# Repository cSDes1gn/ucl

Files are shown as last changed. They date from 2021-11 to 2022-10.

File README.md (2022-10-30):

# Automated Under Cabinet Lighting


Modified: 2022-10

Under cabinet lighting (ucl) control system.

## License
This project is licensed under the terms of the [MIT License](LICENSE)

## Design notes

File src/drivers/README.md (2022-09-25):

# Hardware Peripheral Drivers

Modified: 2022-09

These modules are hardware abstraction layer endpoints for hardware transactions between processors or other hardware peripherals. Hardware drivers should be lightweight and follow the Hardware Proxy design pattern.

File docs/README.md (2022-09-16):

# Documentation

## Installations
```bash
brew tap osx-cross/avr
brew install avr-gcc avrdude
```

## Compile and Flash
Using `CMake` toolchain:
```bash
mkdir build
cd build
cmake ..
make -j
make flash
```

Using `avrdude` and `avr-gcc` utilities
```bash
# compile
avr-gcc main.c usart.c -DF_CPU=16000000 -mmcu=atmega2560 -Wall -Werror -Wextra -Os
# translate to hex
avr-objcopy -j .text -j .data -O ihex a.out my.hex
# flash
avrdude -patmega2560 -cwiring -P/dev/ttyACM0 -b115200 -D -Uflash:w:my.hex:i
```

## Important Links
1. https://www.nongnu.org/avrdude/user-manual/avrdude_toc.html#SEC_Contents
2. https://ww1.microchip.com/downloads/en/devicedoc/atmel-2549-8-bit-avr-microcontroller-atmega640-1280-1281-2560-2561_datasheet.pdf

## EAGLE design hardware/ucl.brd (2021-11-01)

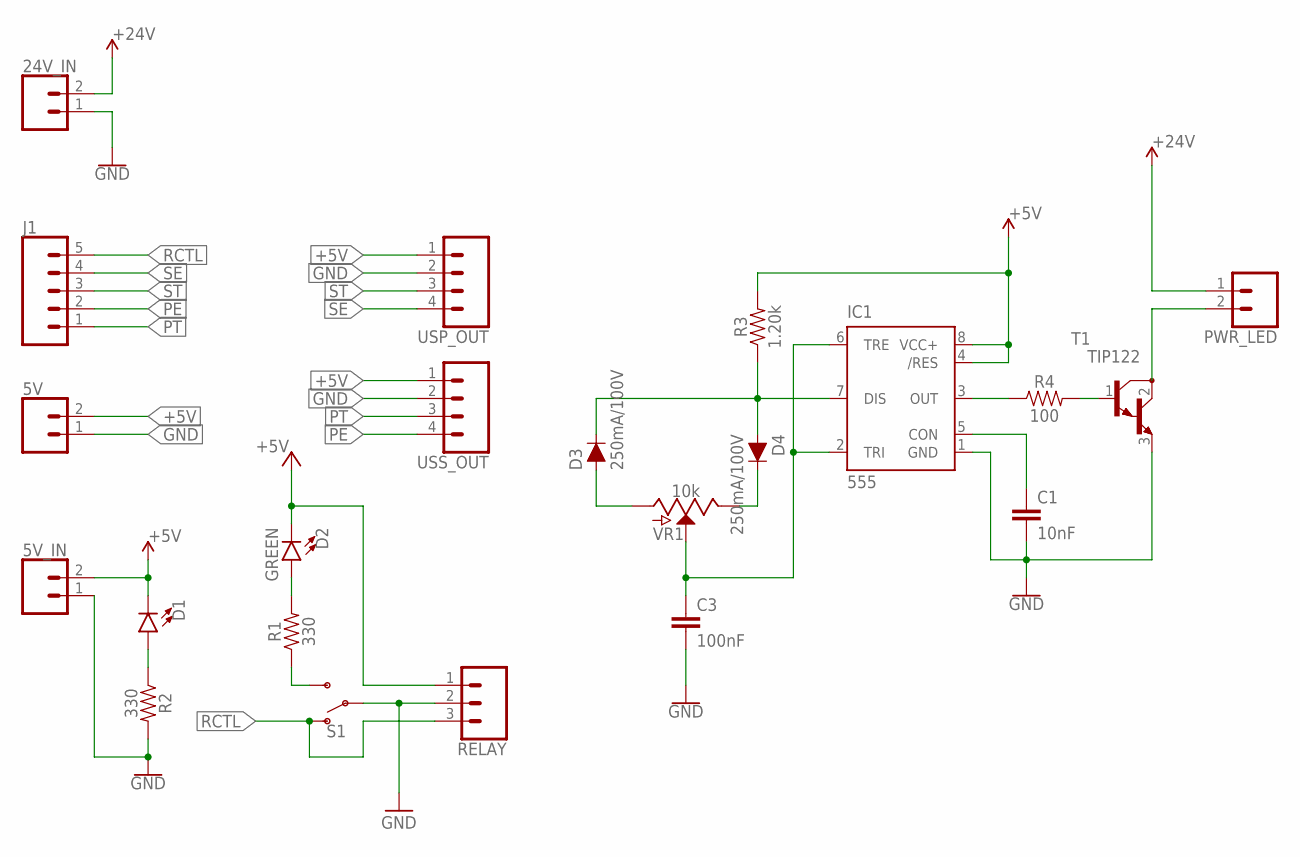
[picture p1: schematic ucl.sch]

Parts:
5V: CONN_02POLAR; MOLEX-1X2
5V_IN, 24V_IN: CONN_02POLAR_LOCK; MOLEX-1X2_LOCK
C1: 10nF; 0402-TIGHT
C3: 100nF; 0402-TIGHT
D1: LED1206; LED-1206
D2: GREEN; LED-1206
D3, D4: 250mA/100V; SOD-323
IC1: 555; SO08
J1: CONN_05; 1X05
PWR_LED: CONN_02POLAR_LOCK; MOLEX-1X2_LOCK
R1, R2: 330; 0603
R3: 1.20k; 0603
R4: 100; 0603
RELAY: CONN_03POLAR_LOCK; MOLEX-1X3_LOCK
S1: SWITCH-SPDT-PTH-11.6X4.0MM-KIT; SWITCH_SPDT_PTH_11.6X4.0MM_KIT
T1: TIP122; TO220
USP_OUT: CONN_04POLAR_LOCK; MOLEX-1X4_LOCK
USS_OUT: CONN_04POLAR_LOCK; MOLEX-1X4_LOCK
VR1: 10k; POT-PTH-ALPS

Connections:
+5V: 5V.2, 5V_IN.2, D1.C, D2.C, IC1.4 (/RES), IC1.8 (VCC+), R3.2, RELAY.1, USP_OUT.1, USS_OUT.1
+24V: 24V_IN.2, PWR_LED.1
GND: 5V.1, 5V_IN.1, 24V_IN.1, C1.2, C3.2, IC1.1 (GND), R2.2, RELAY.2, S1.2, T1.3 (E), USP_OUT.2, USS_OUT.2
unnamed: R1.1, S1.3 (S)
unnamed: D2.A, R1.2
unnamed: D1.A, R2.1
unnamed: D3.C, D4.A, IC1.7 (DIS), R3.1
unnamed: D3.A, VR1.P$3 (A)
unnamed: D4.C, VR1.P$1 (E)
unnamed: C3.1, IC1.2 (TRI), IC1.6 (TRE), VR1.P$2 (S)
unnamed: IC1.3 (OUT), R4.1
unnamed: R4.2, T1.1 (B)
unnamed: C1.1, IC1.5 (CON)
unnamed: PWR_LED.2, T1.2 (C)
PE: J1.2, USS_OUT.4
PT: J1.1, USS_OUT.3
RCTL: J1.5, RELAY.3, S1.1 (O)
SE: J1.4, USP_OUT.4
ST: J1.3, USP_OUT.3

Board: 2 copper layers, 22 parts (0 on the bottom side), 19 nets, no tracks yet.

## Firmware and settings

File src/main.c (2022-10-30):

#include <avr/cpufunc.h>
#include <avr/interrupt.h>
#include <avr/io.h>

#include "encoder.h"
#include "logger.h"
#include "tests.h"
#include "usart.h"

void spinlock(void) {
  while (1) {
    _NOP();
  }
}

int main(void) {
  logger_set_level(LOG_TRACE);
  usart_init();
  encoder_init();
  sei();
  // test_run("EEPROM", test_eeprom);
  // test_run("PWM", test_pwm);
  for (;;) {
    info("Encoder Event: %u", encoder_next_event());
  }
  info("Task complete, entering spinlock.");
  spinlock();
  return 0;
}

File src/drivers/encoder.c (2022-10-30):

#include "encoder.h"

#include <avr/interrupt.h>
#include <avr/io.h>

#include "cbuf.h"
#include "logger.h"

/**
 * @brief All Rotary encoder signals will be handled by PCINT2
 *  SW -> PK3 (PCINT19)
 *  DT -> PK4 (PCINT20)
 *  CLK -> PK5 (PCINT21)
 */

/**
 * @brief Implement table encoding method.　Below are the table state encodings:
 *
 * INVALID = 0
 * CW = 1
 * CCW = 2
 *
 * [PCLK PDT CLK DT | STATE | CODE ]
 *  0 0 0 0 | PASSIVE | 0
 *  0 0 0 1 | CCW     | 2
 *  0 0 1 0 | CW      | 1
 *  0 0 1 1 | INVALID | 0
 *  0 1 0 0 | CW      | 1
 *  0 1 0 1 | PASSIVE | 0
 *  0 1 1 0 | INVALID | 0
 *  0 1 1 1 | CCW     | 2
 *  1 0 0 0 | CCW     | 2
 *  1 0 0 1 | INVALID | 0
 *  1 0 1 0 | PASSIVE | 0
 *  1 0 1 1 | CW      | 1
 *  1 1 0 0 | INVALID | 0
 *  1 1 0 1 | CW      | 1
 *  1 1 1 0 | CCW     | 2
 *  1 1 1 1 | PASSIVE | 0
 */

static volatile uint8_t pre_state = 0;
static volatile enum encoder_event events[ENCODER_EVENT_BUF_LEN];
static cbuf_t cbuffer;

static enum encoder_event encoder_map[] = {
    ENCODER_NULL, ENCODER_CCW,  ENCODER_CW,   ENCODER_NULL,
    ENCODER_CW,   ENCODER_NULL, ENCODER_NULL, ENCODER_CCW,
    ENCODER_CCW,  ENCODER_NULL, ENCODER_NULL, ENCODER_CW,
    ENCODER_NULL, ENCODER_CW,   ENCODER_CCW,  ENCODER_NULL};

/**
 * @brief
 *
 */
ISR(PCINT2_vect) {
  cli();
  if (!(PINK & (1 << PK3))) {
    trace("PUSH");
    cbuf_put(&cbuffer, ENCODER_SW);
  }
  uint8_t re_state = PINK & ((1 << PK4) | (1 << PK5));
  // translate for concat
  re_state >>= 4;
  uint8_t idx = ((pre_state << 2) | re_state) & 0x0f;
  enum encoder_event state = encoder_map[idx];
  switch (state) {
    case ENCODER_CW:
      trace("CW");
      cbuf_put(&cbuffer, ENCODER_CW);
      break;
    case ENCODER_CCW:
      trace("CCW");
      cbuf_put(&cbuffer, ENCODER_CCW);
      break;
    case ENCODER_NULL:
      break;
    default:
      break;
  }
  // save previous state
  pre_state = re_state;
  sei();
}

void encoder_init(void) {
  // set rotary encoder inputs
  DDRK &= ~((1 << PK5) | (1 << PK4) | (1 << PK3));
  // enable pullups
  PORTK |= (1 << PK5) | (1 << PK4) | (1 << PK3);
  // setup interrupt mask for PCINT2 vector
  PCMSK2 |= (1 << PCINT21) | (1 << PCINT20) | (1 << PCINT19);
  // wake scan on PCINT23:16
  PCICR |= (1 << PCIE2);
  // setup event circular buffer
  cbuffer = cbuf_init((uint8_t *)events, ENCODER_EVENT_BUF_LEN);
  trace("encoder driver init success.");
}

void encoder_clear_events(void) {
  cli();
  cbuf_reset(&cbuffer);
  sei();
  trace("reset encoder event queue");
}

enum encoder_event encoder_next_event(void) {
  enum encoder_event event;
  cli();
  if (cbuf_get(&cbuffer, (uint8_t *)&event) == CBUF_EMPTY) {
    event = ENCODER_NULL;
  }
  sei();
  return event;
}

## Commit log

2021-11-01 adding eagle hardware project files
    [ucl.brd, ucl.sch]
2021-11-01 add arduino src code
2022-09-06 sample usart program
2022-09-07 basic cmake toolchain for fuse setting and compilation
2022-09-07 fix fuse target
2022-09-09 write basic eeprom driver
2022-09-09 hack prints
2022-09-10 deprecate arduino api work
2022-09-10 add usart printlf
2022-09-13 add configuration include for general microchip config
    [configuration.h]
2022-09-13 implement 8 bit phase correct PWM stimulus on PL3
    [main.c, pwm.c, pwm.h]
2022-09-15 add pwm sweep test
2022-09-15 fix pwm wake
2022-09-15 pwm_wake bitclear
2022-09-16 first pass at rotary encoder driver
2022-09-25 add basic driver testing framework
2022-09-25 group hardware driver modules
2022-09-25 move re logic to encoder module
2022-09-25 build out encoder event queue
2022-10-16 implement encoder table
2022-10-18 encoder map and ISR PCINT debounce implementation
2022-10-18 interrupt and buffer sync
2022-10-30 deprecate configuration.h
    [configuration.h]
2022-10-30 add case label indents
2022-11-03 add i2c source
2022-11-03 start i2c driver functions
2022-11-07 i2c driver update

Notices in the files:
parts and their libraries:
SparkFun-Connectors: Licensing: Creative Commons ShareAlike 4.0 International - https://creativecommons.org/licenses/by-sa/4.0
